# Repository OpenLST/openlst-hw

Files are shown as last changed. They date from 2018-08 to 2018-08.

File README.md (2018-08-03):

OpenLST Reference Hardware
==========================

This repository contains a KiCad project with a hardware reference
implementation for the OpenLST.  This design is a simplified version
of the Texas Instruments CC1110 432 MHz reference design.  A 1 watt
power amplifier module has been added to increase operating range.
The design is intended for use at 437 MHz, however, it may be modified
for use at other frequencies.

The user is responsible for obtaining and maintaining the necessary
license to operate this radio.  The example project uses frequencies
in the US Amateur Radio UHF band. Transmissions in this band require a
valid FCC license and compliance with CFR Part 97.

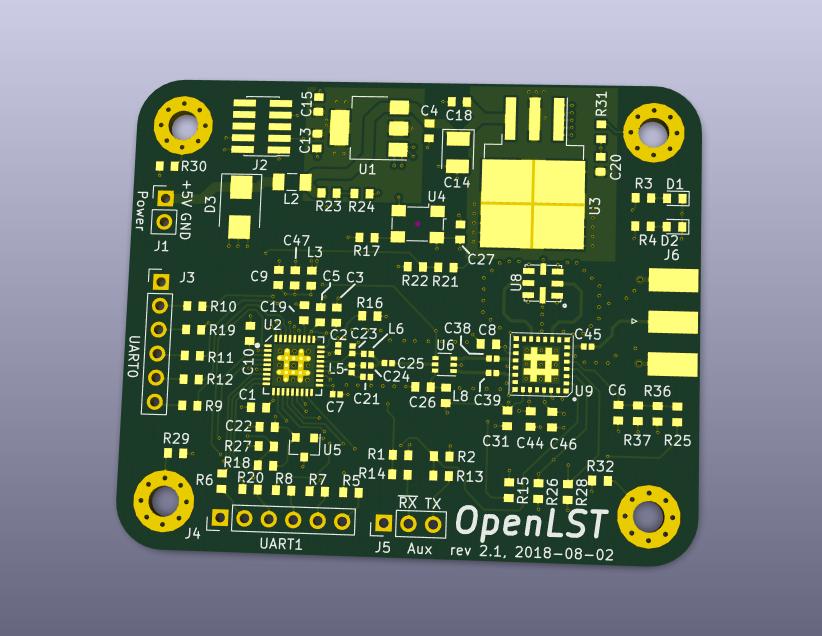
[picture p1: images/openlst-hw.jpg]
board rendering


Contents
--------

This repository contains the following items:

  * [KiCAD 4.0](http://kicad-pcb.org/) project with self-contained part library
  * [Schematic](pdf/openlst-hw.pdf) in PDF form
  * [Bill of materials](bom/) with ordering information for components
  * [Gerber files](gerber/) for PCB fabrication

License & Legal Information
---------------------------

Copyright 2018 Planet Labs Inc. This work is licensed under a
Creative Commons Attribution-ShareAlike 4.0 International License.

This document may contain technology or software the export of which
is or may be restricted by the Export Administration Act and the
Export Administration Regulations (EAR), 15 C.F.R. parts
730-774. Diversion contrary to U.S. law is prohibited.

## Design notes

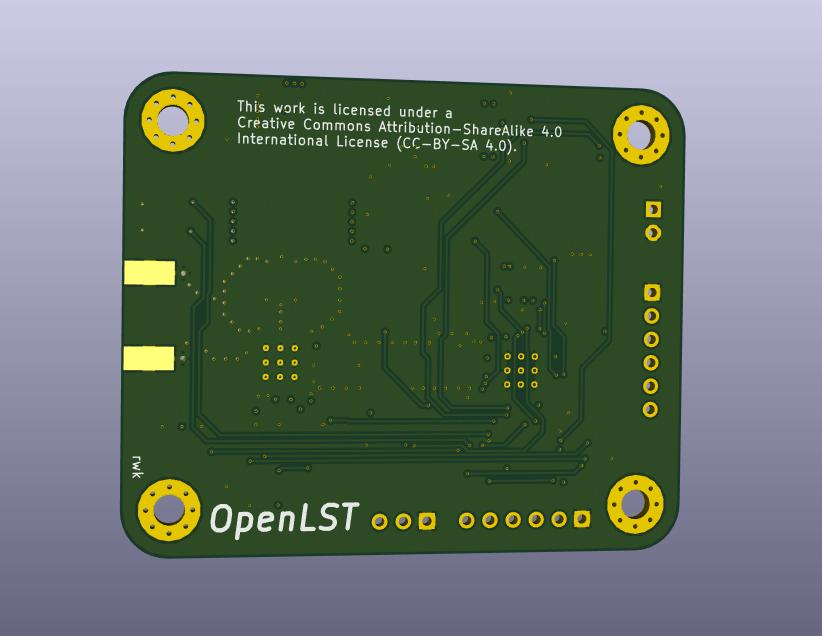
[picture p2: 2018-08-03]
images/openlst-hw-back.jpg

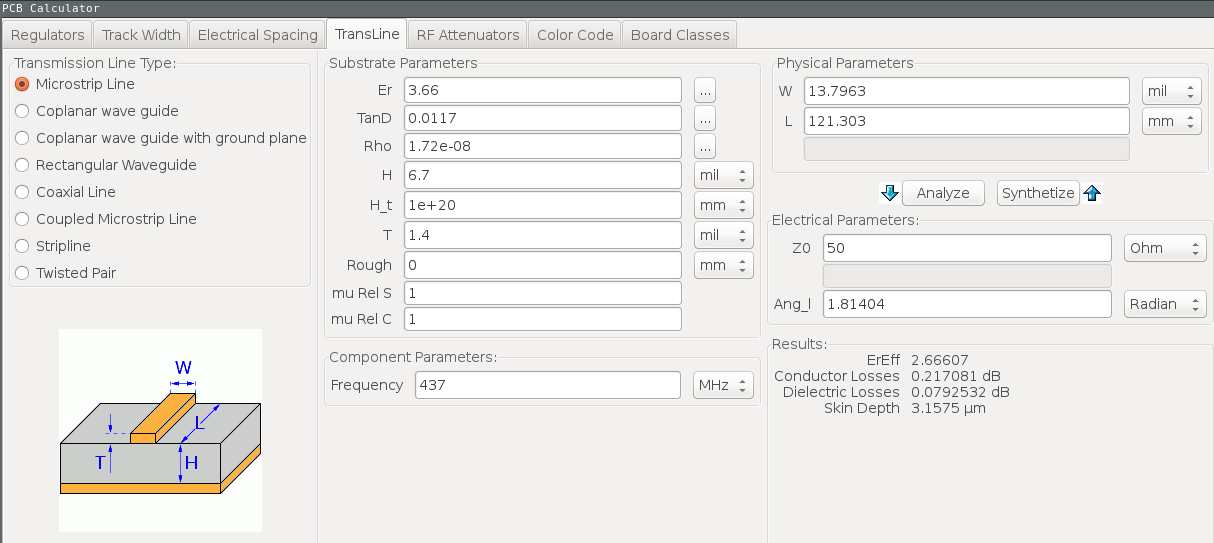
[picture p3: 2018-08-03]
images/osh-park-4-layer-50ohms.png

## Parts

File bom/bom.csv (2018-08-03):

Reference | Value | Footprint | Datasheet | Manuf | ManufPN | Supplier | SupplierPN
L6 | 27n | Inductor_SMD:L_0402_1005Metric | http://search.murata.co.jp/Ceramy/image/img/P02/JELF243A-0050.pdf | Murata | LQW15AN27NJ00D | Digikey | 490-1151-1-ND
J6 | ANT | Connector_Coaxial:SMA_Molex_73251-1153_EdgeMount_Horizontal | https://www.molex.com/pdm_docs/sd/732511150_sd.pdf | Molex | 732511150 | Digikey | WM5534-ND
C45 | 220p | Capacitor_SMD:C_0402_1005Metric | https://api.kemet.com/component-edge/download/datasheet/C0402C221J2GACAUTO.pdf | Kemet | C0402C221J2GACAUTO | Digikey | 399-11552-1-ND
C25 | 220p | Capacitor_SMD:C_0402_1005Metric | https://api.kemet.com/component-edge/download/datasheet/C0402C221J2GACAUTO.pdf | Kemet | C0402C221J2GACAUTO | Digikey | 399-11552-1-ND
C24 | 3.9p | Capacitor_SMD:C_0402_1005Metric | http://search.murata.co.jp/Ceramy/image/img/A01X/G101/ENG/GJM1555C1H3R9CB01-01.pdf | Murata | GJM1555C1H3R9CB01D | Digikey | 490-3097-1-ND
L5 | 27n | Inductor_SMD:L_0402_1005Metric | http://search.murata.co.jp/Ceramy/image/img/P02/JELF243A-0050.pdf | Murata | LQW15AN27NJ00D | Digikey | 490-1151-1-ND
C21 | 220p | Capacitor_SMD:C_0402_1005Metric | https://api.kemet.com/component-edge/download/datasheet/C0402C221J2GACAUTO.pdf | Kemet | C0402C221J2GACAUTO | Digikey | 399-11552-1-ND
U1 | LM1117-3.3 | Package_TO_SOT_SMD:SOT-223-3_TabPin2 | http://www.ti.com/lit/ds/symlink/lm1117.pdf | Texas Instruments | LM1117IMP-3.3/NOPB | Digikey | LM1117IMP-3.3/NOPBCT-ND
C4 | 10u | Capacitor_SMD:C_0603_1608Metric | http://search.murata.co.jp/Ceramy/image/img/A01X/G101/ENG/GRT188C81A106ME13-01.pdf | Murata | GRT188C81A106ME13D | Digikey | 490-12283-1-ND
C13 | 10u | Capacitor_SMD:C_0603_1608Metric | http://search.murata.co.jp/Ceramy/image/img/A01X/G101/ENG/GRT188C81A106ME13-01.pdf | Murata | GRT188C81A106ME13D | Digikey | 490-12283-1-ND
C15 | 0.1u | Capacitor_SMD:C_0603_1608Metric | http://datasheets.avx.com/AutoMLCC.pdf | AVX | 0603YC104K4T4A | Digikey | 478-9382-1-ND
J1 | 5VDC | Connector_PinHeader_2.54mm:PinHeader_1x02_P2.54mm_Vertical
D3 | STPS340U | Diode_SMD:D_SMB | http://www.st.com/content/ccc/resource/technical/document/datasheet/bb/db/21/0c/04/d9/41/a5/CD00000844.pdf/files/CD00000844.pdf/jcr:content/translations/en.CD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 | STMicroelectronics | STPS340U | Digikey | 497-2465-1-ND
L2 | Z=500 @ 100M | Inductor_SMD:L_1206_3216Metric | https://assets.lairdtech.com/home/brandworld/files/MI1206L501R-10.pdf | Laird | MI1206L501R-10 | Digikey | 240-2407-1-ND
C14 | 100u | Capacitor_Tantalum_SMD:CP_EIA-3528-15_AVX-H | http://datasheets.avx.com/TPS.pdf | AVX | TPSB107M010R0400 | Digikey | 478-5231-1-ND
U3 | LT1086-3.6 | Package_TO_SOT_SMD:TO-263-3_TabPin2 | http://www.linear.com/docs/1722 | Linear | LT1086CM-3.6#PBF | Digikey | LT1086CM-3.6#PBF-ND
C46 | 1u | Capacitor_SMD:C_0603_1608Metric | http://www.samsungsem.com/kr/support/product-search/mlcc/CL10B105MO8NNWC.jsp | Samsung | CL10B105MO8NNWC | Digikey | 1276-6524-6-ND
C44 | 1u | Capacitor_SMD:C_0603_1608Metric | http://www.samsungsem.com/kr/support/product-search/mlcc/CL10B105MO8NNWC.jsp | Samsung | CL10B105MO8NNWC | Digikey | 1276-6524-6-ND
U6 | PE4259 | Package_TO_SOT_SMD:SOT-363_SC-70-6 | http://www.psemi.com/pdf/datasheets/pe4259ds.pdf | pSemi | 4259-63 | Digikey | 1046-1011-1-ND
C38 | 220p | Capacitor_SMD:C_0402_1005Metric | https://api.kemet.com/component-edge/download/datasheet/C0402C221J2GACAUTO.pdf | Kemet | C0402C221J2GACAUTO | Digikey | 399-11552-1-ND
C39 | 220p | Capacitor_SMD:C_0402_1005Metric | https://api.kemet.com/component-edge/download/datasheet/C0402C221J2GACAUTO.pdf | Kemet | C0402C221J2GACAUTO | Digikey | 399-11552-1-ND
C26 | 0.1u | Capacitor_SMD:C_0603_1608Metric | http://datasheets.avx.com/AutoMLCC.pdf | AVX | 0603YC104K4T4A | Digikey | 478-9382-1-ND
U2 | CC1110 | openlst:TI_CC_QFN36 | http://www.ti.com/lit/ds/symlink/cc1110-cc1111.pdf | Texas Instruments | CC1110F32RHHR | Digikey | 296-38560-1-ND
U5 | TLV803S | Package_TO_SOT_SMD:SOT-23 | http://www.ti.com/lit/ds/symlink/tlv803.pdf | Texas Instruments | TLV803SDBZR | Digikey | 296-29196-1-ND
R18 | 1K | Resistor_SMD:R_0603_1608Metric | http://www.yageo.com/documents/recent/PYu-RC_Group_51_RoHS_L_9.pdf | Yageo | RC0603JR-071KL | Digikey | 311-1.0KGRCT-ND
C22 | 1n | Capacitor_SMD:C_0603_1608Metric | https://www.murata.com/~/media/webrenewal/support/library/catalog/products/capacitor/mlcc/c03e.ashx | Murata | GCM188R71E102KA37D | Digikey | 490-8016-1-ND
R16 | 56K | Resistor_SMD:R_0603_1608Metric | https://www.seielect.com/Catalog/SEI-RMCF_RMCP.pdf | Stackpole | RMCF0603FT56K0 | Digikey | RMCF0603FT56K0CT-ND
C19 | 1n | Capacitor_SMD:C_0603_1608Metric | https://www.murata.com/~/media/webrenewal/support/library/catalog/products/capacitor/mlcc/c03e.ashx | Murata | GCM188R71E102KA37D | Digikey | 490-8016-1-ND
J2 | CC Prog/Debug | Connector_PinHeader_1.27mm:PinHeader_2x05_P1.27mm_Vertical_SMD | http://suddendocs.samtec.com/prints/ftsh-1xx-xx-xxx-dv-xxx-xxx-mkt.pdf | Samtec | FTSH-105-01-L-DV-K-P | Digikey | SAM9076-ND
R5 | 100 | Resistor_SMD:R_0603_1608Metric | http://www.yageo.com/NewPortal/yageodocoutput?fileName=/pdf/R-Chip/PYu-AC_51_RoHS_L_6.pdf | Yageo | AC0603FR-07100RL | Digikey | YAG3561CT-ND
R6 | 100 | Resistor_SMD:R_0603_1608Metric | http://www.yageo.com/NewPortal/yageodocoutput?fileName=/pdf/R-Chip/PYu-AC_51_RoHS_L_6.pdf | Yageo | AC0603FR-07100RL | Digikey | YAG3561CT-ND
R7 | 100 | Resistor_SMD:R_0603_1608Metric | http://www.yageo.com/NewPortal/yageodocoutput?fileName=/pdf/R-Chip/PYu-AC_51_RoHS_L_6.pdf | Yageo | AC0603FR-07100RL | Digikey | YAG3561CT-ND
R8 | 100 | Resistor_SMD:R_0603_1608Metric | http://www.yageo.com/NewPortal/yageodocoutput?fileName=/pdf/R-Chip/PYu-AC_51_RoHS_L_6.pdf | Yageo | AC0603FR-07100RL | Digikey | YAG3561CT-ND
R9 | 100 | Resistor_SMD:R_0603_1608Metric | http://www.yageo.com/NewPortal/yageodocoutput?fileName=/pdf/R-Chip/PYu-AC_51_RoHS_L_6.pdf | Yageo | AC0603FR-07100RL | Digikey | YAG3561CT-ND
R10 | 100 | Resistor_SMD:R_0603_1608Metric | http://www.yageo.com/NewPortal/yageodocoutput?fileName=/pdf/R-Chip/PYu-AC_51_RoHS_L_6.pdf | Yageo | AC0603FR-07100RL | Digikey | YAG3561CT-ND
R11 | 100 | Resistor_SMD:R_0603_1608Metric | http://www.yageo.com/NewPortal/yageodocoutput?fileName=/pdf/R-Chip/PYu-AC_51_RoHS_L_6.pdf | Yageo | AC0603FR-07100RL | Digikey | YAG3561CT-ND
R12 | 100 | Resistor_SMD:R_0603_1608Metric | http://www.yageo.com/NewPortal/yageodocoutput?fileName=/pdf/R-Chip/PYu-AC_51_RoHS_L_6.pdf | Yageo | AC0603FR-07100RL | Digikey | YAG3561CT-ND
C31 | 0.1u | Capacitor_SMD:C_0603_1608Metric | http://datasheets.avx.com/AutoMLCC.pdf | AVX | 0603YC104K4T4A | Digikey | 478-9382-1-ND
R28 | 1K | Resistor_SMD:R_0603_1608Metric | http://www.yageo.com/documents/recent/PYu-RC_Group_51_RoHS_L_9.pdf | Yageo | RC0603JR-071KL | Digikey | 311-1.0KGRCT-ND
R26 | 1K | Resistor_SMD:R_0603_1608Metric | http://www.yageo.com/documents/recent/PYu-RC_Group_51_RoHS_L_9.pdf | Yageo | RC0603JR-071KL | Digikey | 311-1.0KGRCT-ND
R1 | 1K | Resistor_SMD:R_0603_1608Metric | http://www.yageo.com/documents/recent/PYu-RC_Group_51_RoHS_L_9.pdf | Yageo | RC0603JR-071KL | Digikey | 311-1.0KGRCT-ND
R2 | 1K | Resistor_SMD:R_0603_1608Metric | http://www.yageo.com/documents/recent/PYu-RC_Group_51_RoHS_L_9.pdf | Yageo | RC0603JR-071KL | Digikey | 311-1.0KGRCT-ND
U4 | FOX924 27MHz | Oscillator:Oscillator_SMD_Fordahl_DFAS15-4Pin_5.0x3.2mm | http://www.foxonline.com/pdfs/fox924.pdf | Fox Electronics | FT5HNBPK27.0-T1 | Digikey | 631-1075-1-ND
R17 | 100 | Resistor_SMD:R_0603_1608Metric | http://www.yageo.com/NewPortal/yageodocoutput?fileName=/pdf/R-Chip/PYu-AC_51_RoHS_L_6.pdf | Yageo | AC0603FR-07100RL | Digikey | YAG3561CT-ND
C23 | 3.9p | Capacitor_SMD:C_0402_1005Metric | http://search.murata.co.jp/Ceramy/image/img/A01X/G101/ENG/GJM1555C1H3R9CB01-01.pdf | Murata | GJM1555C1H3R9CB01D | Digikey | 490-3097-1-ND
C27 | 0.1u | Capacitor_SMD:C_0603_1608Metric | http://datasheets.avx.com/AutoMLCC.pdf | AVX | 0603YC104K4T4A | Digikey | 478-9382-1-ND
R15 | DNI | Resistor_SMD:R_0603_1608Metric
D1 | LED | LED_SMD:LED_0603_1608Metric | http://katalog.we-online.de/led/datasheet/150060VS75000.pdf | Wurth | 150060VS75000 | Digikey | 732-4980-1-ND
R3 | 1K | Resistor_SMD:R_0603_1608Metric | http://www.yageo.com/documents/recent/PYu-RC_Group_51_RoHS_L_9.pdf | Yageo | RC0603JR-071KL | Digikey | 311-1.0KGRCT-ND
D2 | LED | LED_SMD:LED_0603_1608Metric | http://katalog.we-online.de/led/datasheet/150060SS75000.pdf | Wurth | 150060SS75000 | Digikey | 732-4979-1-ND
R4 | 1K | Resistor_SMD:R_0603_1608Metric | http://www.yageo.com/documents/recent/PYu-RC_Group_51_RoHS_L_9.pdf | Yageo | RC0603JR-071KL | Digikey | 311-1.0KGRCT-ND
J3 | UART0 | Connector_PinHeader_2.54mm:PinHeader_1x06_P2.54mm_Vertical | http://katalog.we-online.de/em/datasheet/6130xx11121.pdf | Wurth | 61300611121 | Digikey | 732-5319-ND
R19 | DNI | Resistor_SMD:R_0603_1608Metric
J4 | UART1 | Connector_PinHeader_2.54mm:PinHeader_1x06_P2.54mm_Vertical | http://katalog.we-online.de/em/datasheet/6130xx11121.pdf | Wurth | 61300611121 | Digikey | 732-5319-ND
R20 | DNI | Resistor_SMD:R_0603_1608Metric
C1 | 0.1u | Capacitor_SMD:C_0603_1608Metric | http://datasheets.avx.com/AutoMLCC.pdf | AVX | 0603YC104K4T4A | Digikey | 478-9382-1-ND
C10 | 0.1u | Capacitor_SMD:C_0603_1608Metric | http://datasheets.avx.com/AutoMLCC.pdf | AVX | 0603YC104K4T4A | Digikey | 478-9382-1-ND
C2 | 220p | Capacitor_SMD:C_0402_1005Metric | https://api.kemet.com/component-edge/download/datasheet/C0402C221J2GACAUTO.pdf | Kemet | C0402C221J2GACAUTO | Digikey | 399-11552-1-ND
C7 | 220p | Capacitor_SMD:C_0402_1005Metric | https://api.kemet.com/component-edge/download/datasheet/C0402C221J2GACAUTO.pdf | Kemet | C0402C221J2GACAUTO | Digikey | 399-11552-1-ND
C5 | 0.1u | Capacitor_SMD:C_0603_1608Metric | http://datasheets.avx.com/AutoMLCC.pdf | AVX | 0603YC104K4T4A | Digikey | 478-9382-1-ND
C3 | 0.1u | Capacitor_SMD:C_0603_1608Metric | http://datasheets.avx.com/AutoMLCC.pdf | AVX | 0603YC104K4T4A | Digikey | 478-9382-1-ND
C9 | 1u | Capacitor_SMD:C_0603_1608Metric | http://www.samsungsem.com/kr/support/product-search/mlcc/CL10B105MO8NNWC.jsp | Samsung | CL10B105MO8NNWC | Digikey | 1276-6524-6-ND
R21 | 33K | Resistor_SMD:R_0603_1608Metric | http://www.yageo.com/NewPortal/yageodocoutput?fileName=/pdf/R-Chip/PYu-AC_51_RoHS_L_6.pdf | Yageo | AC0603FR-0733KL | Digikey | YAG3598CT-ND
R22 | 10K | Resistor_SMD:R_0603_1608Metric | http://www.yageo.com/documents/recent/PYu-RC_Group_51_RoHS_L_9.pdf | Yageo | RC0603JR-0710KL | Digikey | 311-10KGRCT-ND
R23 | 33K | Resistor_SMD:R_0603_1608Metric | http://www.yageo.com/NewPortal/yageodocoutput?fileName=/pdf/R-Chip/PYu-AC_51_RoHS_L_6.pdf | Yageo | AC0603FR-0733KL | Digikey | YAG3598CT-ND
R24 | 10K | Resistor_SMD:R_0603_1608Metric | http://www.yageo.com/documents/recent/PYu-RC_Group_51_RoHS_L_9.pdf | Yageo | RC0603JR-0710KL | Digikey | 311-10KGRCT-ND
R36 | 5K6 | Resistor_SMD:R_0603_1608Metric | https://www.seielect.com/Catalog/SEI-RMCF_RMCP.pdf | Stackpole | RMCF0603FT5K60 | Digikey | RMCF0603FT5K60CT-ND
R37 | 3K3 | Resistor_SMD:R_0603_1608Metric | https://www.seielect.com/Catalog/SEI-RMCF_RMCP.pdf | Stackpole | RMCF0603FT3K30 | Digikey | RMCF0603FT3K30CT-ND
C47 | 1u | Capacitor_SMD:C_0603_1608Metric | http://www.samsungsem.com/kr/support/product-search/mlcc/CL10B105MO8NNWC.jsp | Samsung | CL10B105MO8NNWC | Digikey | 1276-6524-6-ND
C18 | 10u | Capacitor_SMD:C_0603_1608Metric | http://search.murata.co.jp/Ceramy/image/img/A01X/G101/ENG/GRT188C81A106ME13-01.pdf | Murata | GRT188C81A106ME13D | Digikey | 490-12283-1-ND
C20 | 10u | Capacitor_SMD:C_0603_1608Metric | http://search.murata.co.jp/Ceramy/image/img/A01X/G101/ENG/GRT188C81A106ME13-01.pdf | Murata | GRT188C81A106ME13D | Digikey | 490-12283-1-ND
L8 | Z=1k @ 100M | Inductor_SMD:L_0603_1608Metric | http://katalog.we-online.de/pbs/datasheet/74279266.pdf | Wurth | 74279266 | Digikey | 732-4484-1-ND
L3 | Z=1k @ 100M | Inductor_SMD:L_0603_1608Metric | http://katalog.we-online.de/pbs/datasheet/74279266.pdf | Wurth | 74279266 | Digikey | 732-4484-1-ND
J5 | Control Outputs | Connector_PinHeader_2.54mm:PinHeader_1x03_P2.54mm_Vertical
R14 | 100 | Resistor_SMD:R_0603_1608Metric | http://www.yageo.com/NewPortal/yageodocoutput?fileName=/pdf/R-Chip/PYu-AC_51_RoHS_L_6.pdf | Yageo | AC0603FR-07100RL | Digikey | YAG3561CT-ND
R13 | 100 | Resistor_SMD:R_0603_1608Metric | http://www.yageo.com/NewPortal/yageodocoutput?fileName=/pdf/R-Chip/PYu-AC_51_RoHS_L_6.pdf | Yageo | AC0603FR-07100RL | Digikey | YAG3561CT-ND
U8 | STA1120A | openlst:SAW-8_3.8mm |  | Sawtron | STA1120A
R25 | DNI | Resistor_SMD:R_0603_1608Metric
R27 | 33K | Resistor_SMD:R_0603_1608Metric | http://www.yageo.com/NewPortal/yageodocoutput?fileName=/pdf/R-Chip/PYu-AC_51_RoHS_L_6.pdf | Yageo | AC0603FR-0733KL | Digikey | YAG3598CT-ND
C6 | 0.1u | Capacitor_SMD:C_0603_1608Metric | http://datasheets.avx.com/AutoMLCC.pdf | AVX | 0603YC104K4T4A | Digikey | 478-9382-1-ND
C8 | 0.1u | Capacitor_SMD:C_0603_1608Metric | http://datasheets.avx.com/AutoMLCC.pdf | AVX | 0603YC104K4T4A | Digikey | 478-9382-1-ND
U9 | RFFM6403 | openlst:Qorvo_LGA_28_ThermalVias | https://www.qorvo.com/products/d/da000805 | Qorvo | RFFM6403SB
MK1 | M3_Hole | MountingHole:MountingHole_3.2mm_M3_Pad_Via
R29 | DNI | Resistor_SMD:R_0603_1608Metric
R31 | DNI | Resistor_SMD:R_0603_1608Metric
MK3 | M3_Hole | MountingHole:MountingHole_3.2mm_M3_Pad_Via
MK2 | M3_Hole | MountingHole:MountingHole_3.2mm_M3_Pad_Via
R30 | DNI | Resistor_SMD:R_0603_1608Metric
R32 | DNI | Resistor_SMD:R_0603_1608Metric
MK4 | M3_Hole | MountingHole:MountingHole_3.2mm_M3_Pad_Via

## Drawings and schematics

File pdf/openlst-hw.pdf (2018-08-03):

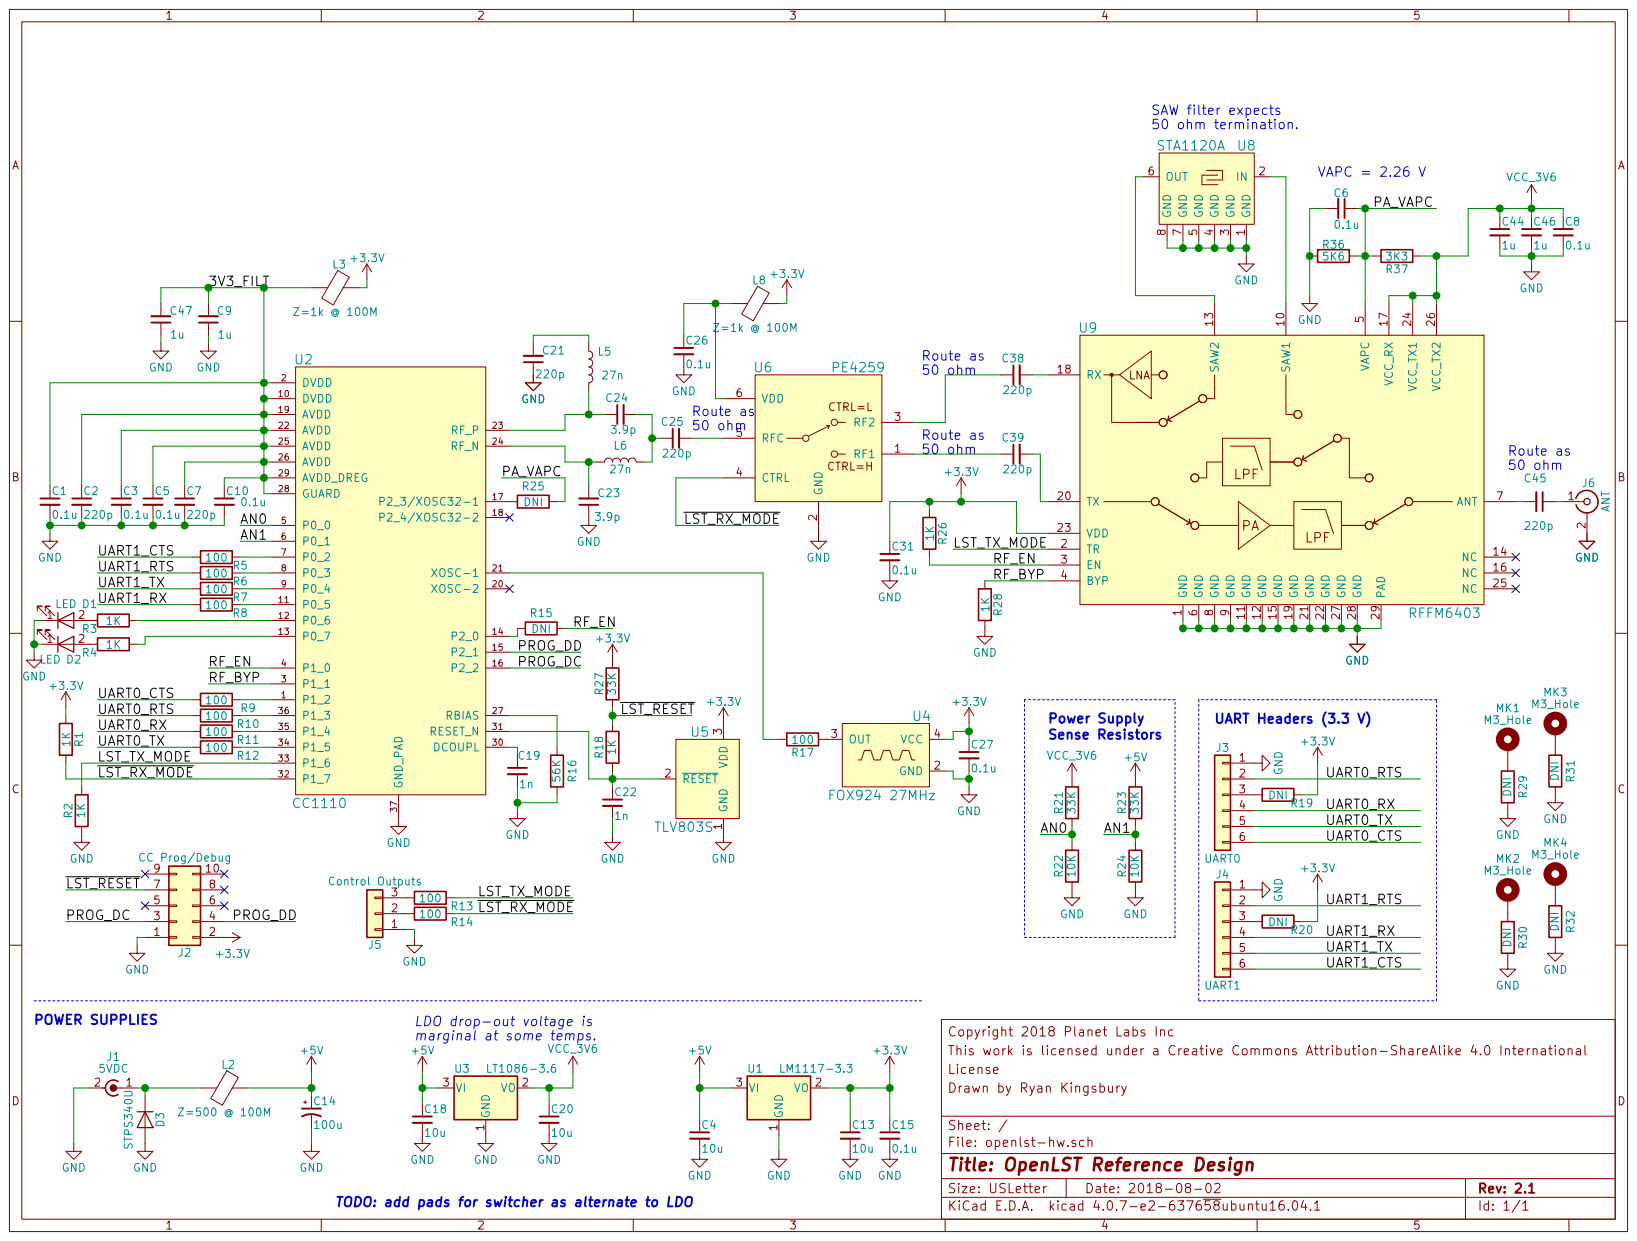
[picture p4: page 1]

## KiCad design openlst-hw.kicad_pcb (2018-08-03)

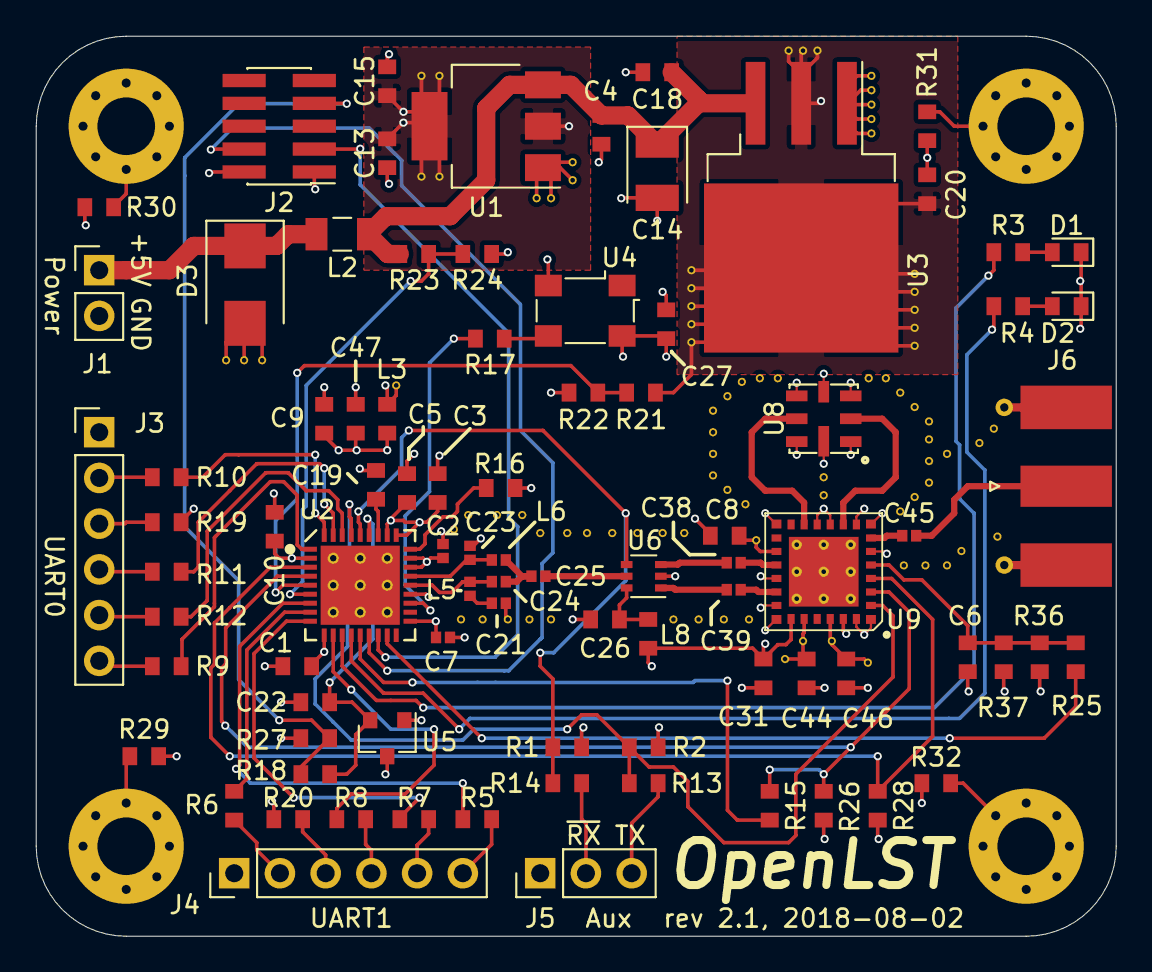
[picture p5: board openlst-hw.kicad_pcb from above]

Board: 4 copper layers, 60.0 x 50.0 mm, 90 parts (0 on the bottom side), 65 nets.

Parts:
C1, C3, C5, C6, C8, C10, C15, C26, C27, C31: 0.1u; C_0603_1608Metric
C2, C7, C21, C25, C38, C39, C45: 220p; C_0402_1005Metric
C4, C13, C18, C20: 10u; C_0603_1608Metric
C9, C44, C46, C47: 1u; C_0603_1608Metric
C14: 100u; CP_EIA-3528-15_AVX-H
C19, C22: 1n; C_0603_1608Metric
C23, C24: 3.9p; C_0402_1005Metric
D1, D2: LED; LED_0603_1608Metric
D3: STPS340U; D_SMB
J1: 5VDC; PinHeader_1x02_P2.54mm_Vertical
J2: CC Prog/Debug; PinHeader_2x05_P1.27mm_Vertical_SMD
J3: UART0; PinHeader_1x06_P2.54mm_Vertical
J4: UART1; PinHeader_1x06_P2.54mm_Vertical
J5: Control Outputs; PinHeader_1x03_P2.54mm_Vertical
J6: ANT; SMA_Molex_73251-1153_EdgeMount_Horizontal
L2: Z=500 @ 100M; L_1206_3216Metric
L3, L8: Z=1k @ 100M; L_0603_1608Metric
L5, L6: 27n; L_0402_1005Metric
MK1, MK2, MK3, MK4: M3_Hole; MountingHole_3.2mm_M3_Pad_Via
R1, R2, R3, R4, R18, R26, R28: 1K; R_0603_1608Metric
R5, R6, R7, R8, R9, R10, R11, R12, R13, R14, R17: 100; R_0603_1608Metric
R15, R19, R20, R25, R29, R30, R31, R32: DNI; R_0603_1608Metric
R16: 56K; R_0603_1608Metric
R21, R23, R27: 33K; R_0603_1608Metric
R22, R24: 10K; R_0603_1608Metric
R36: 5K6; R_0603_1608Metric
R37: 3K3; R_0603_1608Metric
U1: LM1117-3.3; SOT-223-3_TabPin2
U2: CC1110; TI_CC_QFN36
U3: LT1086-3.6; TO-263-3_TabPin2
U4: FOX924 27MHz; Oscillator_SMD_Fordahl_DFAS15-4Pin_5.0x3.2mm
U5: TLV803S; SOT-23
U6: PE4259; SOT-363_SC-70-6
U8: STA1120A; SAW-8_3.8mm
U9: RFFM6403; Qorvo_LGA_28_ThermalVias

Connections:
+3V3: C13.1, C15.1, C27.1, C31.1, J2.2, L3.1, L8.1, R1.1, R19.1, R20.1, R26.1, R27.2, U1.2, U4.4, U5.3, U9.23
+5V: C4.1, C14.1, C18.1, L2.1, R23.2, U1.3, U3.3
/3V3_FILT: C1.1, C2.1, C3.1, C5.1, C7.1, C9.2, C10.1, C47.2, L3.2, U2.2, U2.10, U2.19, U2.22, U2.25, U2.26, U2.28, U2.29
/AN0: R21.1, R22.2, U2.5
/AN1: R23.1, R24.2, U2.6
/LST_TX_MODE: R2.2, R13.1, U2.33, U9.2
/PA_VAPC: C6.1, R25.1, R36.1, R37.2, U9.5
/PROG_DC: J2.3, U2.16
/PROG_DD: J2.4, U2.15
/RF_BYP: R28.1, U2.3, U9.4
/RF_EN: R15.1, R26.2, U2.4, U9.3
/UART0_CTS: J3.6, R9.2
/UART0_RTS: J3.2, R10.2
/UART0_RX: J3.4, R11.2
/UART0_TX: J3.5, R12.2
/UART1_CTS: J4.6, R5.2
/UART1_RTS: J4.2, R6.2
/UART1_RX: J4.4, R8.2
/UART1_TX: J4.5, R7.2
/~LST_RESET: J2.7, R18.2, R27.1
/~LST_RX_MODE: R1.2, R14.1, U2.32, U6.4
GND: C1.2, C2.2, C3.2, C4.2, C5.2, C6.2, C7.2, C8.2, C9.1, C10.2, C13.2, C14.2, C15.2, C18.2, C19.2, C20.2, C21.1, C22.2, C23.1, C26.2, C27.2, C31.2, C44.2, C46.2, C47.1, D1.1, D2.1, D3.2, J1.2, J2.1, J3.1, J4.1, J5.1, J6.2, R2.1, R16.1, R22.1, R24.1, R28.2, R29.1, R30.1, R31.1, R32.1, R36.2, U1.1, U2.37, U3.1, U4.2, U5.1, U6.2, U8.1, U8.3, U8.4, U8.5, U8.7, U8.8, U9.1, U9.6, U9.8, U9.9, U9.11, U9.12, U9.15, U9.19, U9.21, U9.22, U9.27, U9.28, U9.29
unnamed: C19.1, U2.30
unnamed: C21.2, L5.1
unnamed: C22.1, R18.1, U2.31, U5.2
unnamed: C23.2, L6.1, U2.24
unnamed: C24.1, L5.2, U2.23
unnamed: C24.2, C25.1, L6.2
unnamed: C25.2, U6.5
unnamed: C26.1, L8.2, U6.6
unnamed: C38.1, U6.3
unnamed: C38.2, U9.18
unnamed: C39.1, U6.1
unnamed: C39.2, U9.20
unnamed: C45.1, J6.1
unnamed: C45.2, U9.7
unnamed: D1.2, R3.1
unnamed: D2.2, R4.1
unnamed: D3.1, J1.1, L2.2
unnamed: J3.3, R19.2
unnamed: J4.3, R20.2
unnamed: J5.2, R14.2
unnamed: J5.3, R13.2
unnamed: MK1.1, R29.2
unnamed: MK2.1, R30.2
unnamed: MK3.1, R31.2
unnamed: MK4.1, R32.2
unnamed: R3.2, U2.12
unnamed: R4.2, U2.13
unnamed: R5.1, U2.7
unnamed: R6.1, U2.8
unnamed: R7.1, U2.9
unnamed: R8.1, U2.11
unnamed: R9.1, U2.1
unnamed: R10.1, U2.36
unnamed: R11.1, U2.35
unnamed: R12.1, U2.34
unnamed: R15.2, U2.14
unnamed: R16.2, U2.27
unnamed: R17.1, U4.3
unnamed: R17.2, U2.21
unnamed: R25.2, U2.17
unnamed: U8.2, U9.10
unnamed: U8.6, U9.13
VCC_3V6: C8.1, C20.1, C44.1, C46.1, R21.2, R37.1, U3.2, U9.17, U9.24, U9.26

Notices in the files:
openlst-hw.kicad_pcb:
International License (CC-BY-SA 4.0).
